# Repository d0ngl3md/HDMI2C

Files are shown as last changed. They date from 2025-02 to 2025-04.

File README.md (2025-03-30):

# HDMI2C
My adventure into I2C devices over HDMI
after running set up script, you are in i2c group, but .. theres a glitchy thing, might need need to log out and back in, though you are now member to the i2c group. as a member to the i2c group, with group ownership over the i2c devices, you should not need root to run programs accessing the i2c bus. thats the thought anyway. 

STEMMA 4-Pin I2C (both standard & STEMMA QT) <br>
<br>Black for GND. 
<br>Red for V+ 
<br>Blue for SDA. 
<br>Yellow for SCL

<br>
I just obsurved a singular device with several addresses, might try to write that into a serach option.
<br>
LCD 16x4, i2c base addresses, 0x20 thru 0x27
<br><br>
I had been messing with this on a display port to HDMI addapter, and could not get it to work.
When I switched over to a straight throught HDMI, it worked instantly!
<br>
sudo apt-install python3-dev
pip install smbus2

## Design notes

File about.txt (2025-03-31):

draft: Kicad 9.0 schematic for HDMI-A female to female I2C tap
we can make this even better with edid via eeprom. thatway we can have hot plug detection, device id etc.

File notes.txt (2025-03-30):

Given the sheer number of possibilites, sensors, integrations,  theres unlimited possibilities.
Current:
i2c LCD, listening to computer audio, (I dont have any i2c ADCs to run a microphone, so computer audio is fine.)
pip install pyaudio
fails.
sudo apt install portaudio19-dev
then
pip install pyaudio

Success!

################
sudo apt install python3-dev

############ OK I Think i get it now! ###########
the reffernce image here, https://blog.danman.eu/emulating-hdmi-connection/
they reason this guy uses an eeprom is to enumerate the i2c device, which garners the plug detection (hot plug functionality )
the EDID, on the i2c bus, is a memory device at address 0x50, which the kernel has a driver predefined to listen on, and 
await responses which define the device plugged in. its weird right. the hot plug function is based on polling a non hot plug tech.
SO IF I get an i2c memory device, and assign it address 0x50, I should be able to make my own hotplugable HDMI devices without 
having to do a kernel module hack, or write a bunch of weird scripts to handle how the bus gets enumerated. 

ok, and get-edid is a superiour tool for ID of bus devices with i2c memory IDs

################################### DERPS BELOW ##########################################

ok, been hitting this for a minute. got some issues. The constants are the device addresses, but on any given system, 
the bus could differ, which means we're editing code every time we want to run a program on a different computer.
That is a pain in the butt.

I tried writing a class library to take addresses, and return busses, but this isnt working properly yet. 
Auto enumeration is the goal, or something close to that. 

it could be my own ignorance, but the enumeration of i2c devices is not automatic on linux systems, its more like
a device responds to a probe if present. There are differnt means of probing, and various devices respond in different ways.
need to look more at the quick-write functions which are for some devices, and other functional methods.

################ I2C IS NOT HOT PLUG TECHNOLOGY BUT HDMI IS ##################
tried using HPD as a detectio method, but I think its more complex than HOD being high or low.
maybe a kernel driver mod could report that. As is, you get the status of the connection for an enumerated 
device. since my device is non enumerable, it says disconnected. maybe its not too complex to make an enumerable device?
Then i could use HDMI hot plug events to detect the controlers with i2c devices....
###############################################################################

Ok so that is important, as it means we dont know when or where an i2c technology will attach to a system.
it will respond to poling, (probably)  where, and when is a mystery. I2C is not event driven, there is no protocol 
level or electrical level detection, and no IRQs.

So the goal is to make it less of a mystery. 

What I might do is write a script that logs the system default, no attached devices.
 so then what? when we're looking for devices on busses, maybe look at the log first?
The full scan operation lenghth can vary alot. its like 77 addresses on N-buses.

So... ah.. lets see, I think the HDMI I2C bus (though variant from computer to computer) is constant for any specific computers
hardware. So HDMI is hot plugable, which means the device on video could be used to detect a device.

Additionaly, we could do:

$ ls /sys/class/drm/card0-HDMI-A-*

which will give you bus assignments to the HDMI port.
this might vary, on systems with graphics cards, or multiple HDMI ports.
still it would tell you a more probable list of devices to search, rather than scanning all the i2c devices.
might be able to make a more intelligent script too, once I see what a system breaking that logic would do.
Else:
$ ls /sys/class/drm/card0-HDMI-A-* | grep i2c-
i2c-1
i2c-2
i2c-4

for example. my laptop has busses 6,7 as the HDMI i2c busses. its sorta weird, that I have 2 or 3 hdmi devices listed on a system with 1 HDMI
port. maybe its a CPU support thing. IDK.

## It happend: the i2c bus numbers changed when I installed the NVidea kernel drivers.
   still, its only 2 ports. so maybe on a system with a stable kernel/ setup, the busses dont change?
############# On this idea of using HDMI hotplug detection and kernel drivers: ########################################
Getting into this ugly gray area, of hardware detection, but what Im tring to do now is use CPU and GPU detection to read registers related to HPD.

sudo apt install intel-gpu-tools

system specific: x86_64 integrated intel graphics only: HPB status on register 0x6111C

bleh, all this is ugly

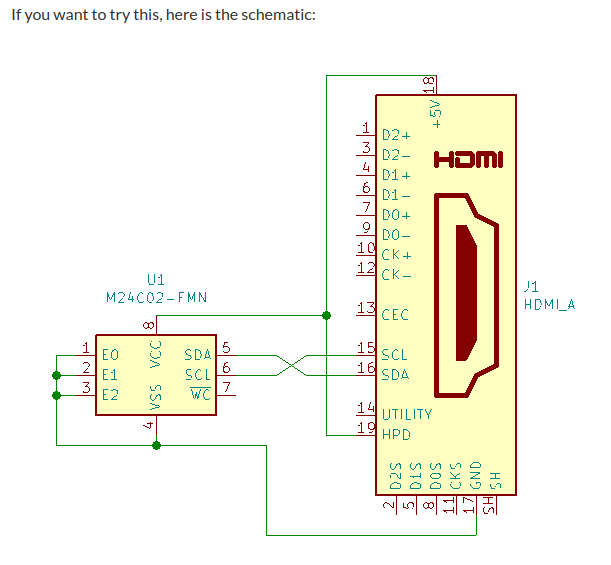
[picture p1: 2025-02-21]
refference.png

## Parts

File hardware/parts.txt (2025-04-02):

https://pl-1.org/getproductfile.axd?id=5711&filename=ATMLH412.pdf
pulled from vga monitor

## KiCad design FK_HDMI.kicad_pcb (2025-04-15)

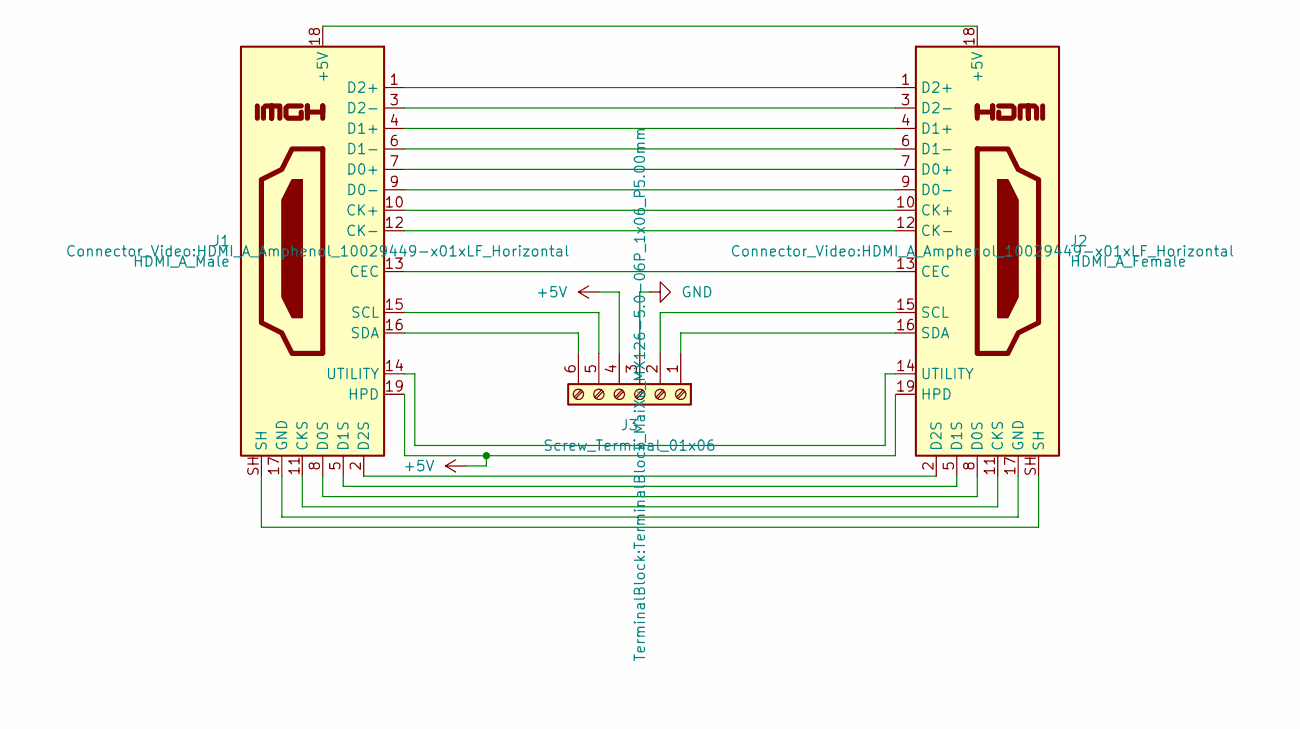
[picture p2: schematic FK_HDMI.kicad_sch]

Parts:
J1: HDMI_A_Male; HDMI_A_Amphenol_10029449-x01xLF_Horizontal
J2: HDMI_A_Female; HDMI_A_Amphenol_10029449-x01xLF_Horizontal
J3: Screw_Terminal_01x06; TerminalBlock_MaiXu_MX126-5.0-06P_1x06_P5.00mm

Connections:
+5V: J1.19 (HPD), J2.19 (HPD), J3.4
GND: J3.3
unnamed: J1.18 (+5V), J2.18 (+5V)
unnamed: J1.13 (CEC), J2.13 (CEC)
unnamed: J1.10 (CK+), J2.10 (CK+)
unnamed: J1.12 (CK-), J2.12 (CK-)
unnamed: J1.11 (CKS), J2.11 (CKS)
unnamed: J1.7 (D0+), J2.7 (D0+)
unnamed: J1.9 (D0-), J2.9 (D0-)
unnamed: J1.8 (D0S), J2.8 (D0S)
unnamed: J1.4 (D1+), J2.4 (D1+)
unnamed: J1.6 (D1-), J2.6 (D1-)
unnamed: J1.5 (D1S), J2.5 (D1S)
unnamed: J1.1 (D2+), J2.1 (D2+)
unnamed: J1.3 (D2-), J2.3 (D2-)
unnamed: J1.2 (D2S), J2.2 (D2S)
unnamed: J1.17 (GND), J2.17 (GND)
unnamed: J1.SH, J2.SH
unnamed: J1.15 (SCL), J3.5
unnamed: J1.16 (SDA), J3.6
unnamed: J1.14 (UTILITY), J2.14 (UTILITY)
unnamed: J2.15 (SCL), J3.2
unnamed: J2.16 (SDA), J3.1

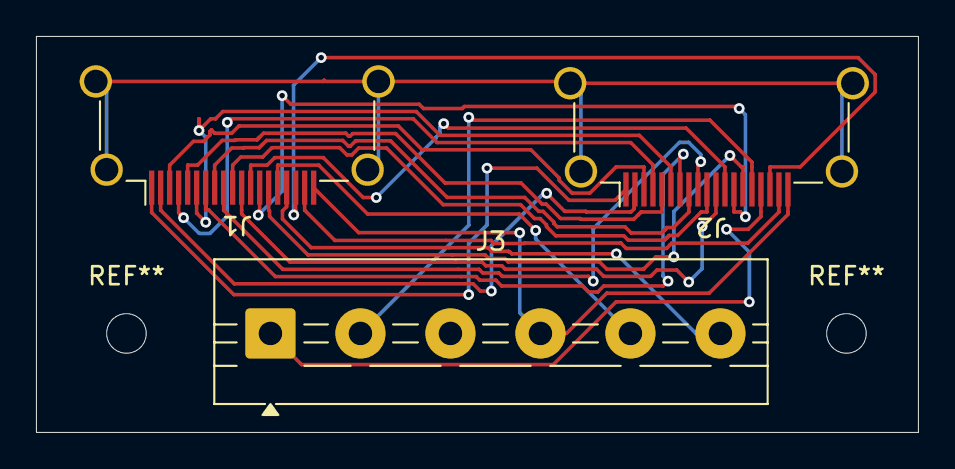
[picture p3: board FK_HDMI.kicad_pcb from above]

Board: 2 copper layers, 49.0 x 22.0 mm, 3 parts (0 on the bottom side), 22 nets.

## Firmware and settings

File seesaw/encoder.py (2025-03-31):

#!/usr/bin/env python3
from smbus2 import SMBus, i2c_msg
import struct
from time import sleep
import sys
"""
The seesaw ecoders have some differences from the encoders used in V1 SketchyEtch:
first, i2c addresssing
second, memory, they can save the value of where they last were. ... for the entire time they are powered.
    removing the device from power, theyll forget thier position.
    but you can turn the knobs with this program off, and thyell keep storing positional data.
    which is really interesting.
    
might implement the buttons though I dont anticapte using them. 
There is also an RGB neopixel on each encoder.
"""
BYTES = 4
I2C_BUS = 4        # Change if needed
I2C_ADDR = 0x36
I2C_ADDR2 = 0x37
SEESAW_ENCODER_BASE = 0x11
SEESAW_ENCODER_POSITION = 0x30
SEESAW_ENCODER_DELTA = 0x40

def read_register(bus, addr, base, reg, length):
    try:
        # Write base + reg
        write = i2c_msg.write(addr, [base, reg])
        read = i2c_msg.read(addr, length)
        bus.i2c_rdwr(write, read)
        return list(read)
    except OSError as e:
        # ok still a logical error here, you can have the right bus on the wrong addr, or the wrong bus on the right addr or...
        # want to fail gracefully, but with good descriptions.
        print(f"I2C Bus 0x{I2C_BUS:02X} not responding.")
        print(f"I2C Address 0x{addr:02X} not responding.")
        print("Check your Bus and addresses.")
        sys.exit(1)      

def read_encoder_position(bus):
    data = read_register(bus, SEESAW_ENCODER_BASE, SEESAW_ENCODER_POSITION, I2C_BUS)
    pos = struct.unpack(">i", bytes(data))[0]
    return pos

def read_encoder_delta(bus):
    data = read_register(bus, SEESAW_ENCODER_BASE, SEESAW_ENCODER_DELTA, I2C_BUS)
    delta = struct.unpack(">i", bytes(data))[0]
    return delta

if __name__ == "__main__":
    with SMBus(I2C_BUS) as bus:
        try:
            while True:
                data1 = read_register(bus, I2C_ADDR, SEESAW_ENCODER_BASE, SEESAW_ENCODER_POSITION, BYTES)
                data2 = read_register(bus, I2C_ADDR2, SEESAW_ENCODER_BASE, SEESAW_ENCODER_POSITION, BYTES)
                for addr in [I2C_ADDR, I2C_ADDR2]:
                    data = read_register(bus, addr, SEESAW_ENCODER_BASE, SEESAW_ENCODER_POSITION, BYTES)
                    pos = struct.unpack(">i", bytes(data))[0]
                    print(f"Encoder {addr:02X} Position: {pos}")

                #pos = read_encoder_position(bus)
                #delta = read_encoder_delta(bus)
                #print(f"Position: {pos}, Delta: {delta}")
                sleep(0.1)
        except KeyboardInterrupt:
            print("\nExiting...")

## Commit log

2025-03-29 kicad hdmi tap files
    [FK_HDMI.kicad_pcb, FK_HDMI.kicad_sch]
2025-04-15 Add files via upload
    Did pcb design in kicad 9. Used plugins pcb way, and freerouter, also assigned footprints to schematic components.
    [FK_HDMI.kicad_pcb, FK_HDMI.kicad_sch, hdmitap-panel.kicad_pcb]
